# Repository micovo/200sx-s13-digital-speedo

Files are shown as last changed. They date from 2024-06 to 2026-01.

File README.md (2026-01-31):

# Nissan 180SX/200SX/240SX S13 Digital Speedo
This repository contains reverse-engineered schematics of Nissan S13 digital speedometer (VFD display).

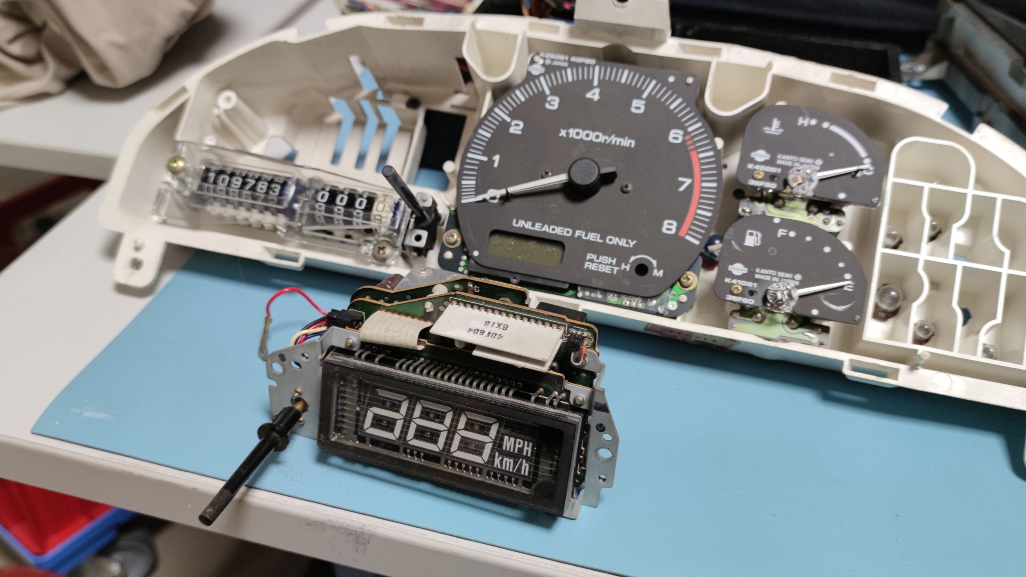
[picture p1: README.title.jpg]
Digital speedo foto Digital speedometer foto


The schematics description is available on my blog:

https://blog.michalhrouda.cz/2022/02/nissan-180sx-240sx-s13-digital-speedometer-schematics/

## Changelog

### REV3

- Project updated to KiCAD 9.0.0

- MainBoard - CONN1 and CONN2 numbering pattern fix to Nissan style (Second row of pins was mirrored)

- MainBoard, PowerBoard - HUD_2_POWER??? and HUD_3_POWER??? renamed to HUD_2_POWER and HUD_3_POWER (Confirmed by manual)

- PowerBoard - TRANS label added to transformer. It was not clear what "TRANS" in CONN6A1 signals description was referring to.

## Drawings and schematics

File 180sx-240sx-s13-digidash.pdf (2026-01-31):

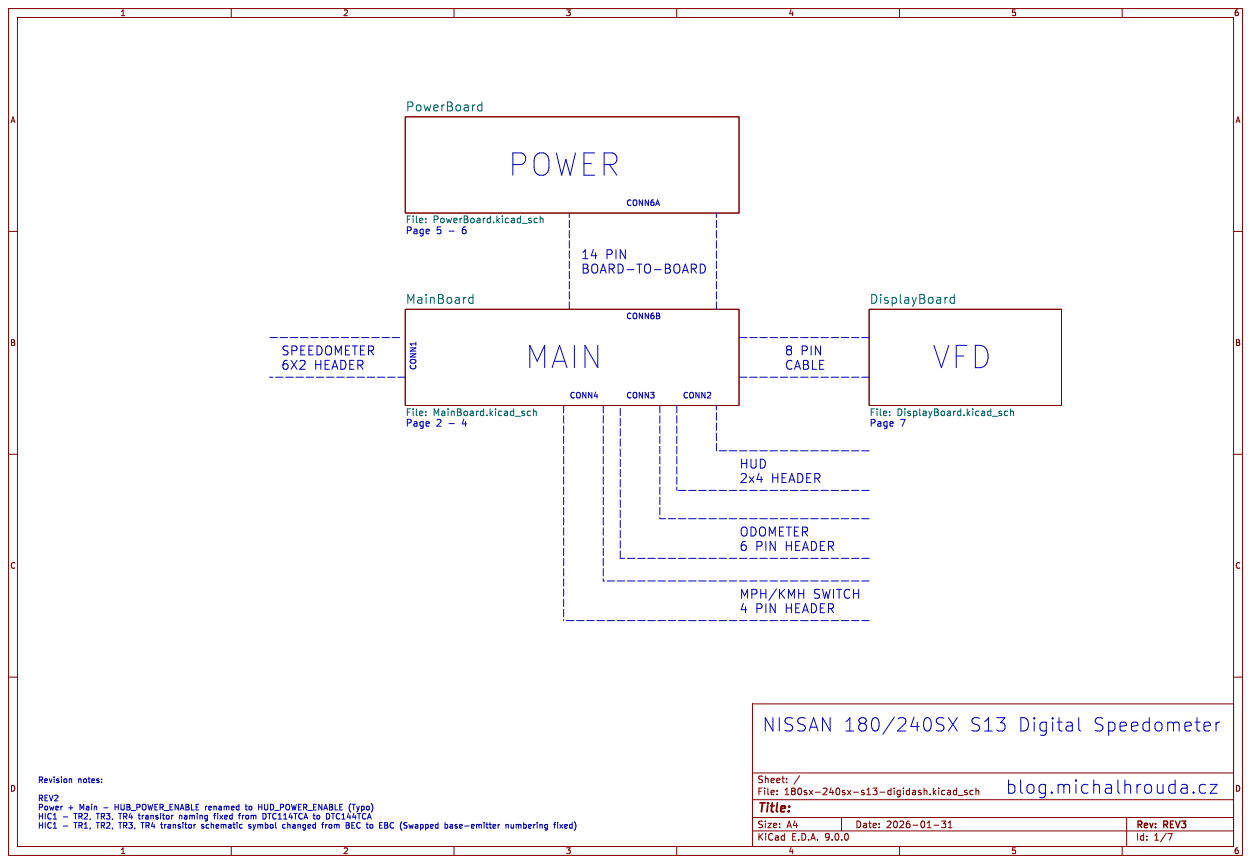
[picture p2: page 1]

Id: 1/7 Title: File: 180sx-240sx-s13-digidash.kicad_sch Sheet: /

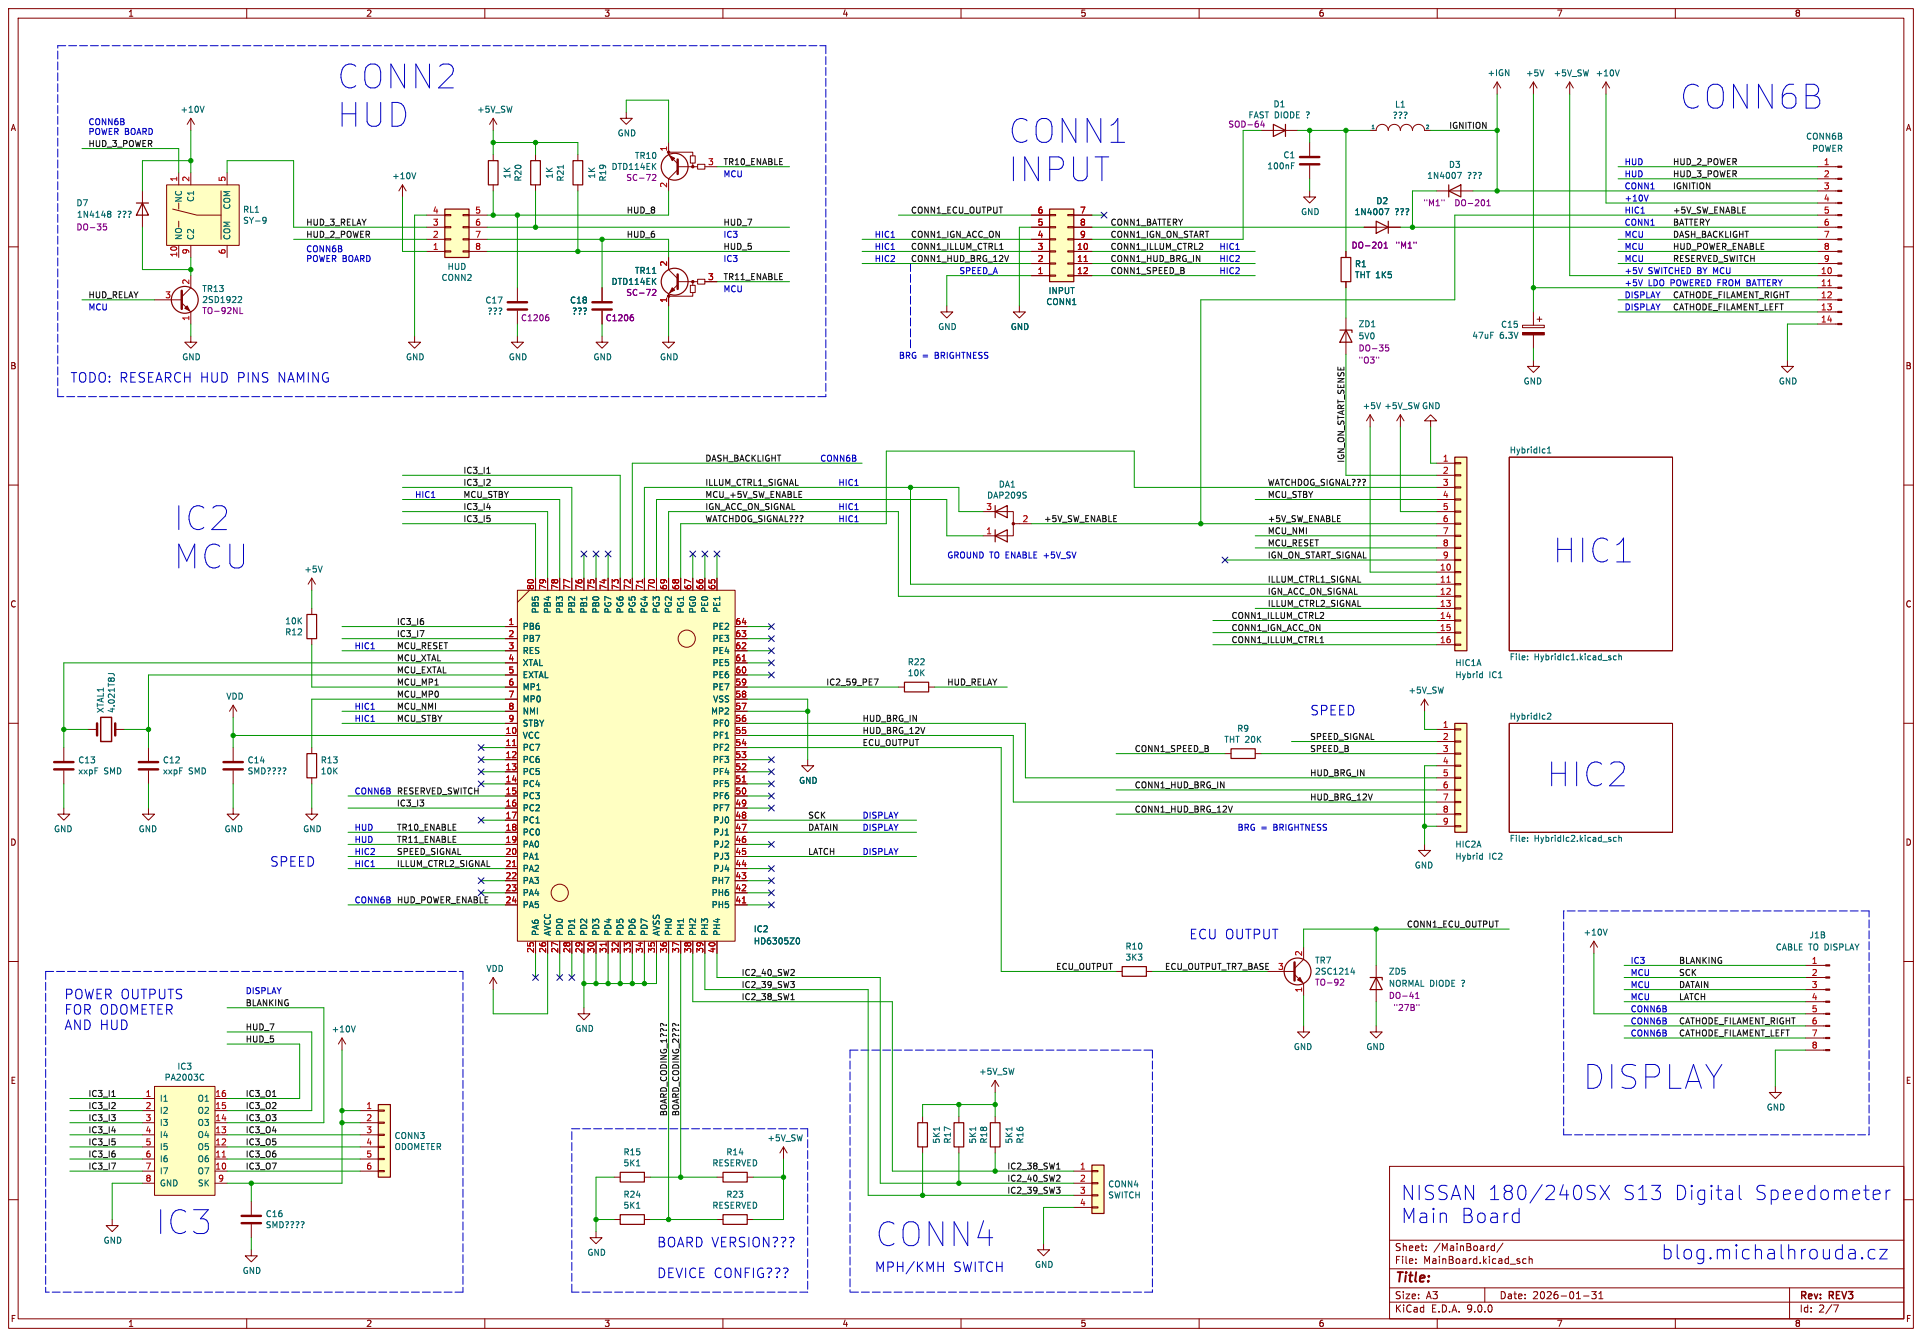
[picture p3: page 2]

SPEED_A DISPLAY MPH/KMH SWITCH

TODO: RESEARCH HUD PINS NAMING

J1B CABLE TO DISPLAY GND

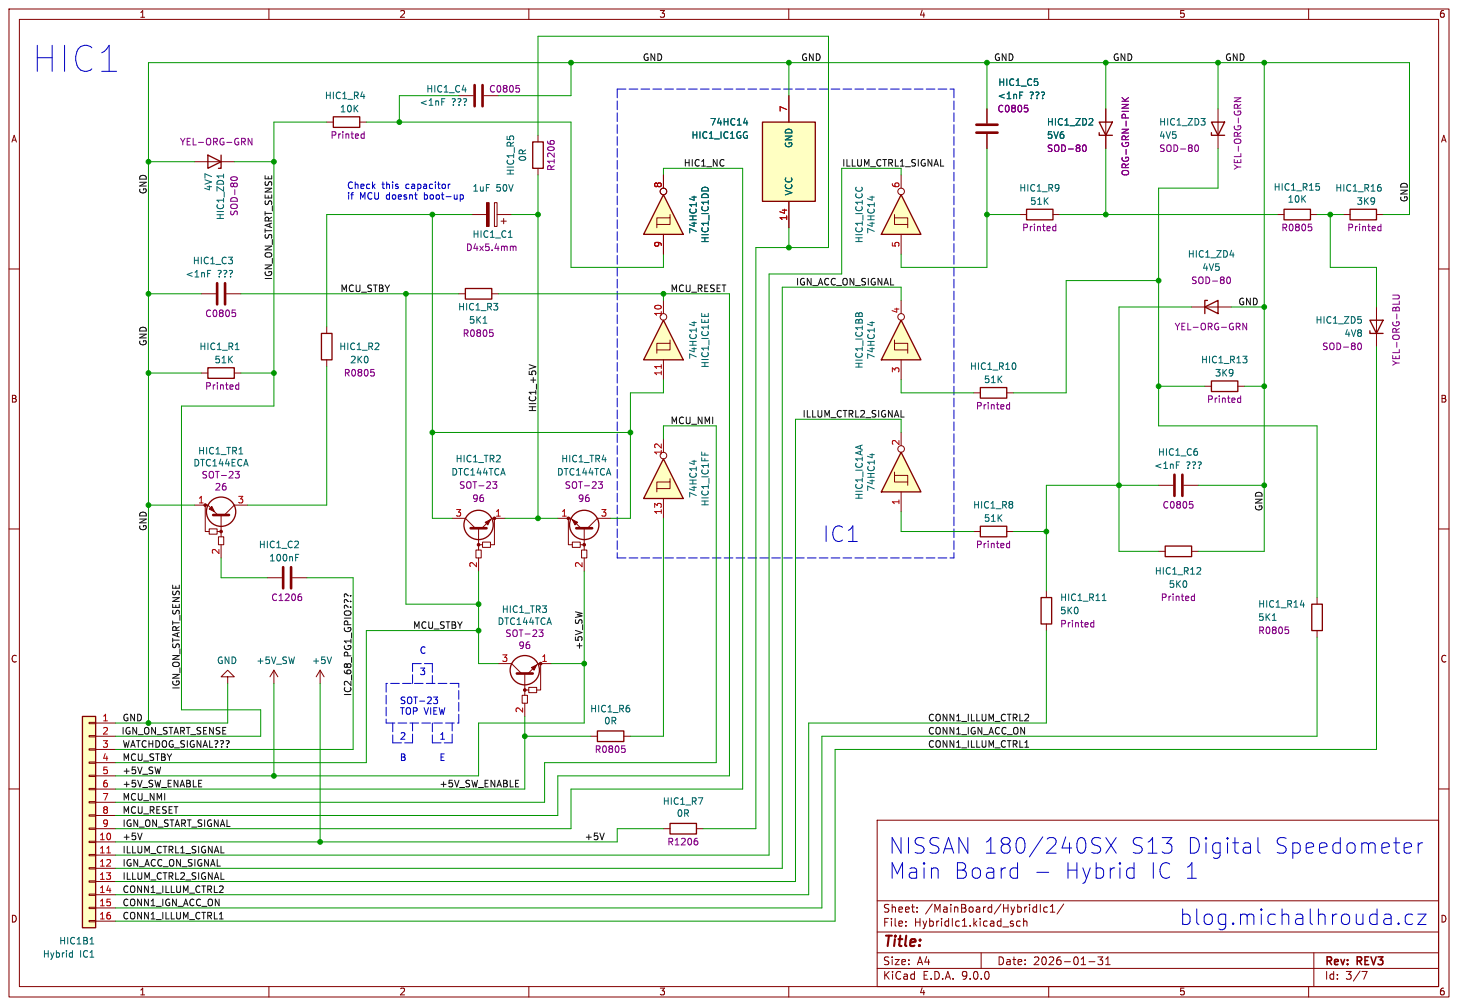
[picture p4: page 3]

Check this capacitor
if MCU doesnt boot-up
5K1 R0805 HIC1_C1

4V5 SOD-80 YEL-ORG-GRN

Main Board - Hybrid IC 1

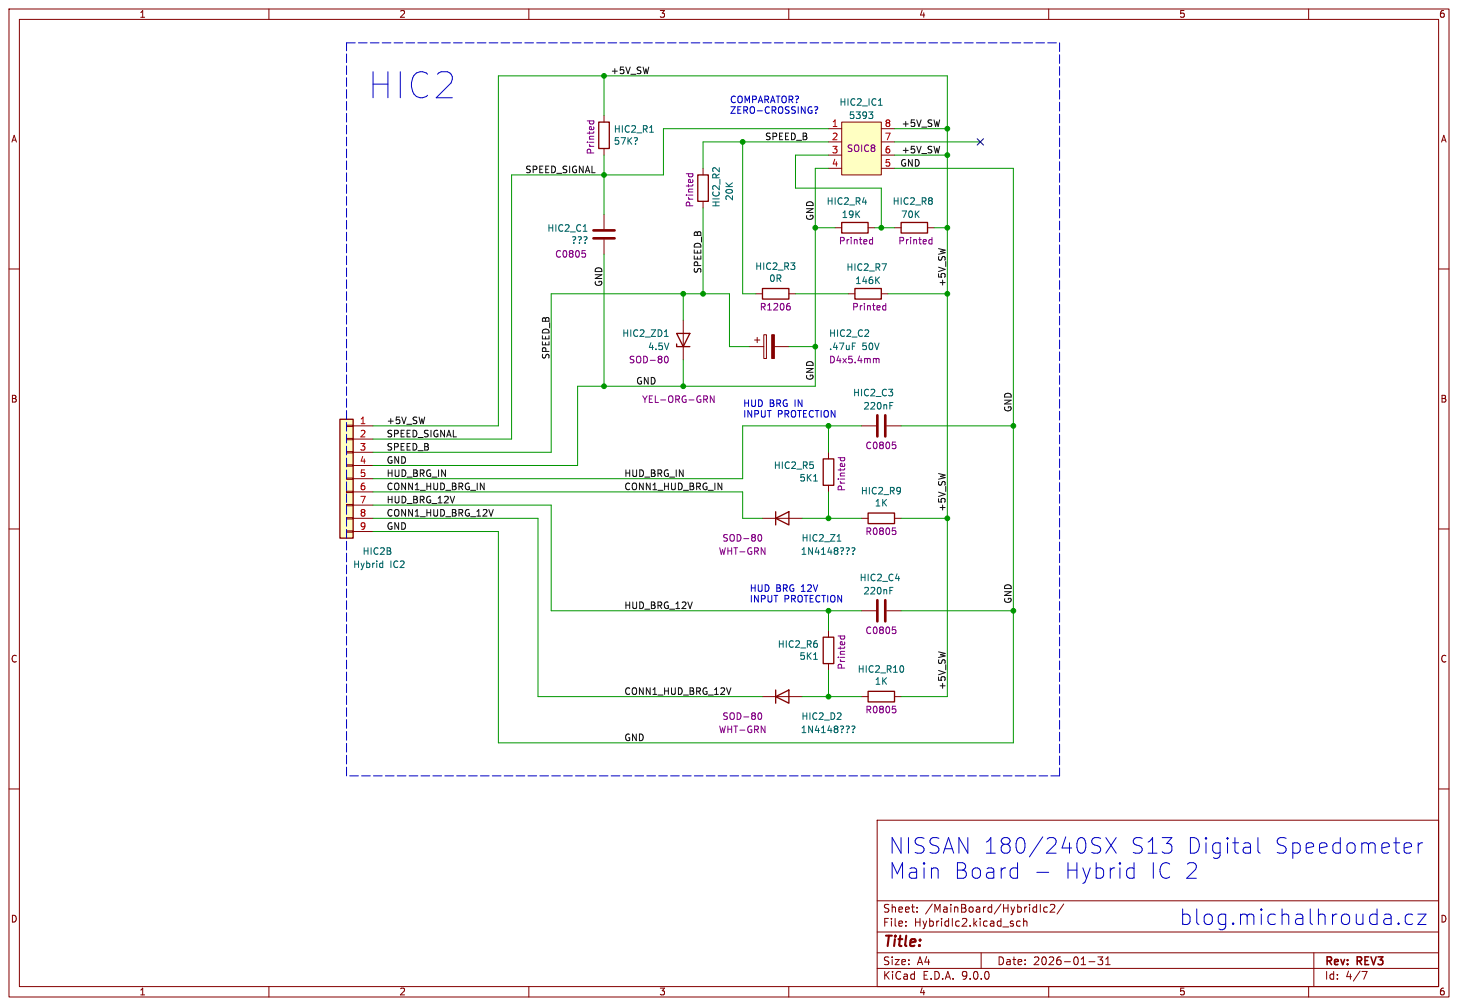
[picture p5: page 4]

SOD-80 YEL-ORG-GRN

Id: 4/7 Title: File: HybridIc2.kicad_sch Sheet: /MainBoard/HybridIc2/ HIC2_R9

Main Board - Hybrid IC 2

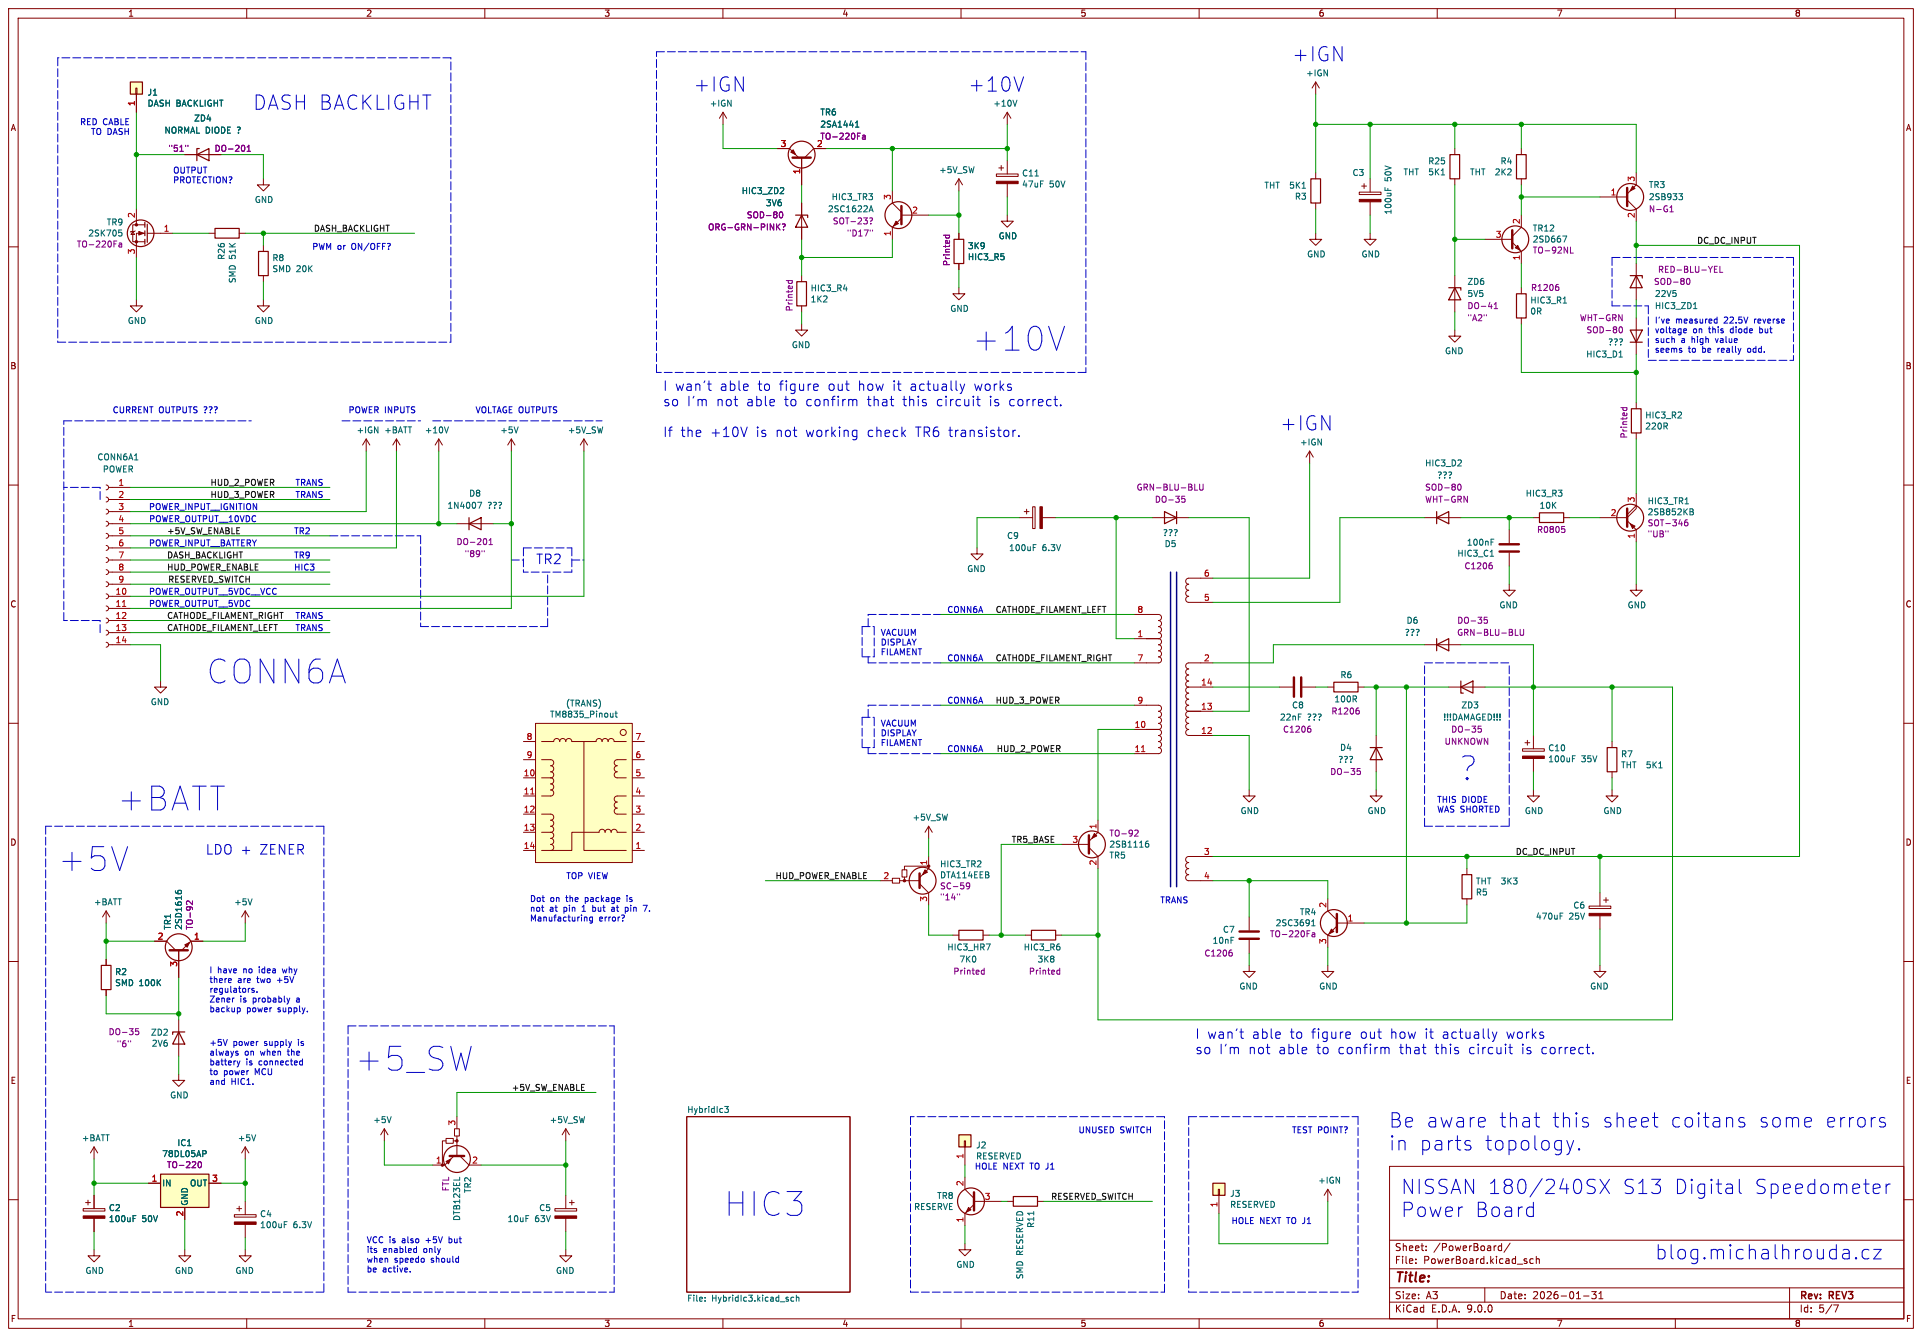
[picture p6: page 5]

OUTPUT PROTECTION? LDO + ZENER

seems to be really odd. +10V

3V6 SOD-80 ORG-GRN-PINK?

??? DO-35 GRN-BLU-BLU GND

HIC3_ZD1
I've measured 22.5V reverse
voltage on this diode but such a high value

??? SOD-80 WHT-GRN GND

so I'm not able to confirm that this circuit is correct.

If the +10V is not working check TR6 transistor.

!!!DAMAGED!!! DO-35 UNKNOWN GND

FILAMENT VCC is also +5V but

THIS DIODE WAS SHORTED

I have no idea why
there are two +5V

+5V power supply is always on when the

Be aware that this sheet coitans some errors
in parts topology.
Power Board

its enabled only when speedo should

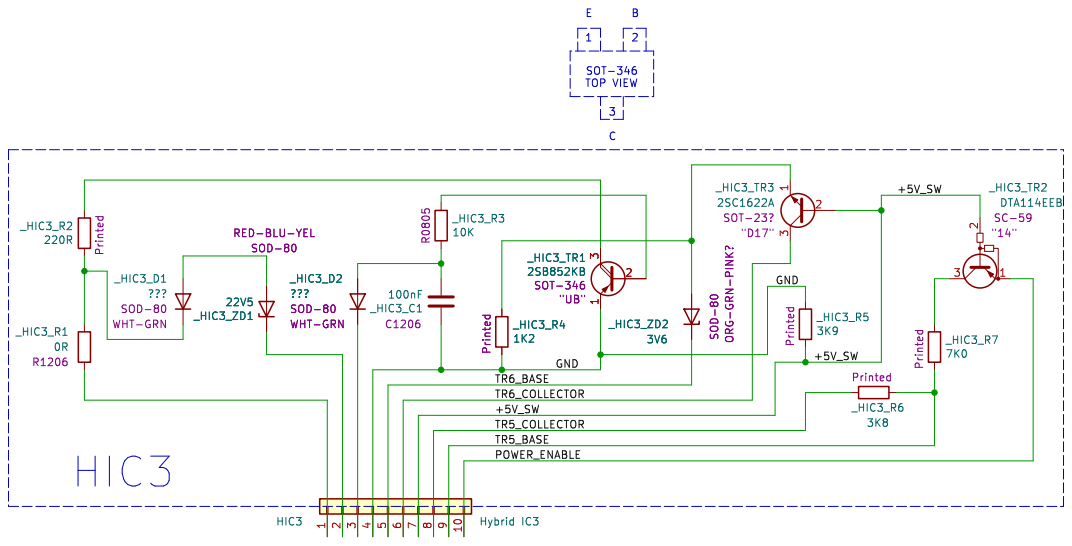
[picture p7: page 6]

Main Board - Hybrid IC 3

Id: 6/7 Title: File: HybridIc3.kicad_sch Sheet: /PowerBoard/HybridIc3/

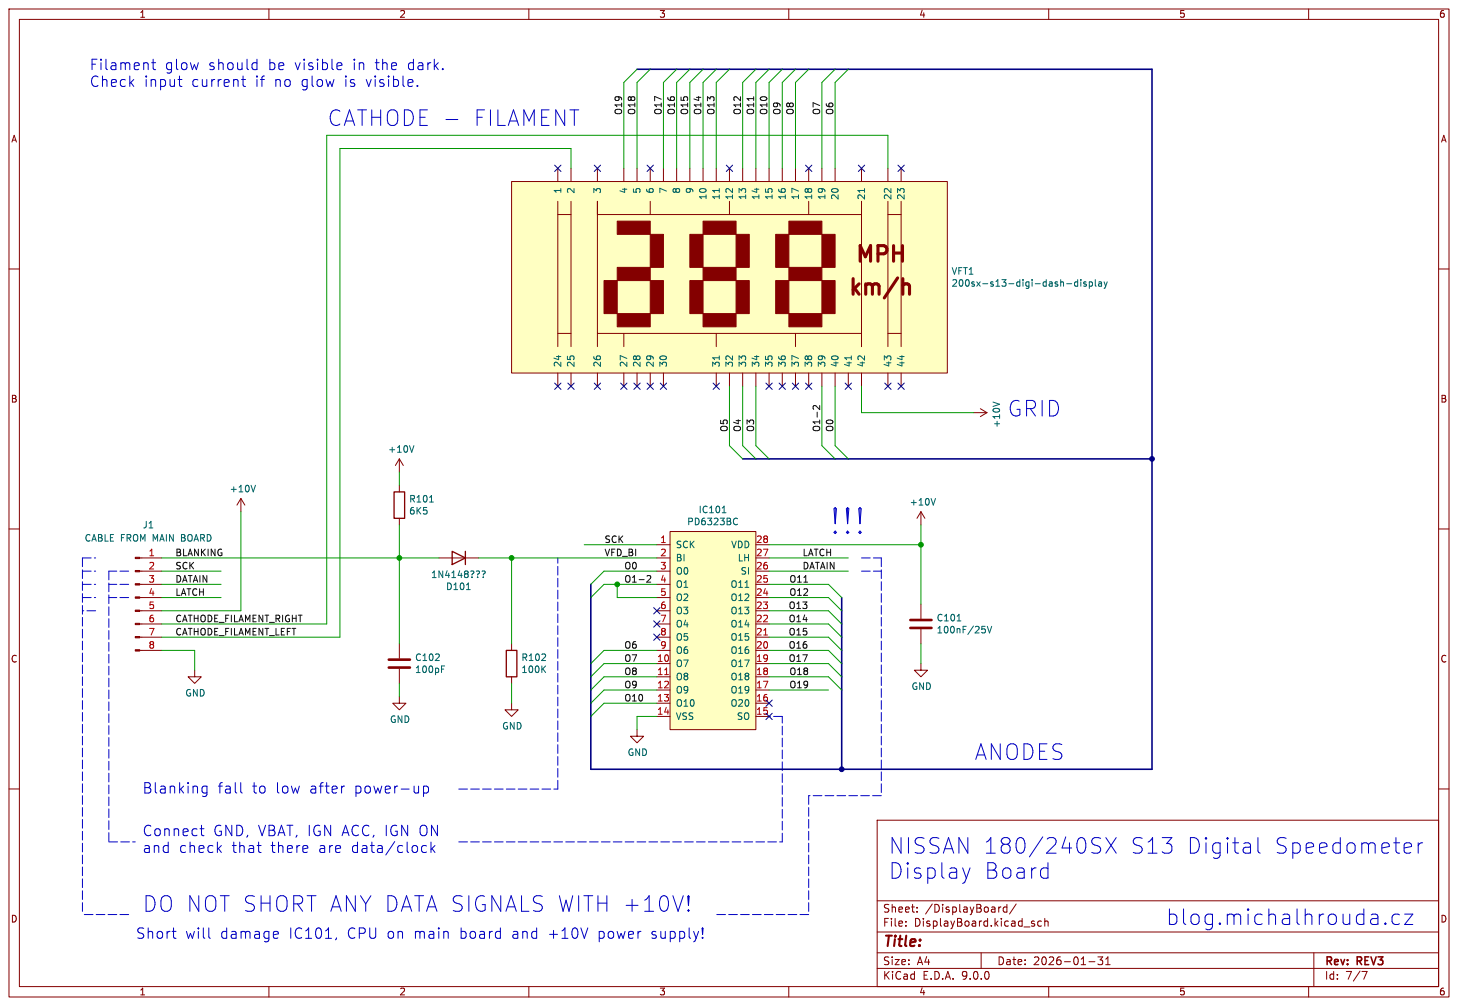
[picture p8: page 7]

Filament glow should be visible in the dark.
Check input current if no glow is visible.

J1 CABLE FROM MAIN BOARD

Id: 7/7 Title: File: DisplayBoard.kicad_sch Sheet: /DisplayBoard/ C102

Blanking fall to low after power-up

Connect GND, VBAT, IGN ACC, IGN ON
and check that there are data/clock

DO NOT SHORT ANY DATA SIGNALS WITH +10V!

Short will damage IC101, CPU on main board and +10V power supply!

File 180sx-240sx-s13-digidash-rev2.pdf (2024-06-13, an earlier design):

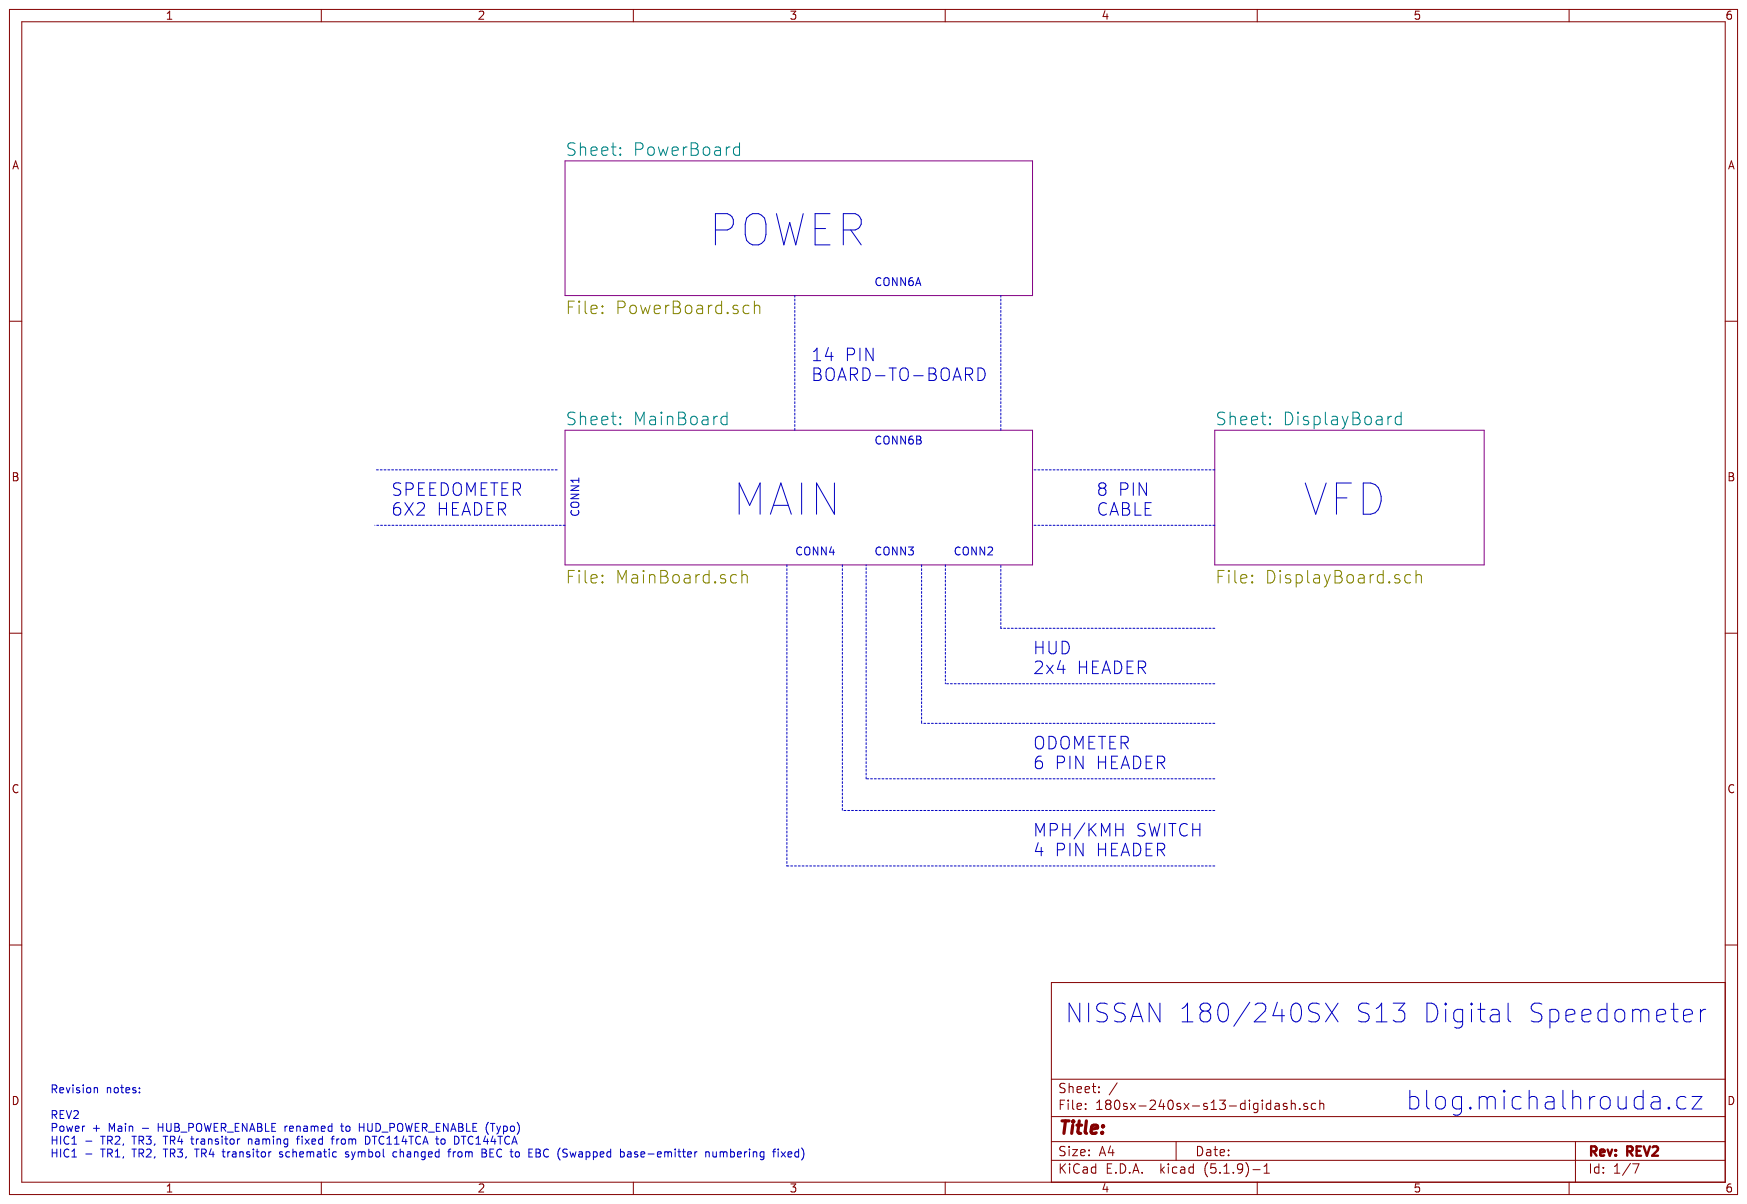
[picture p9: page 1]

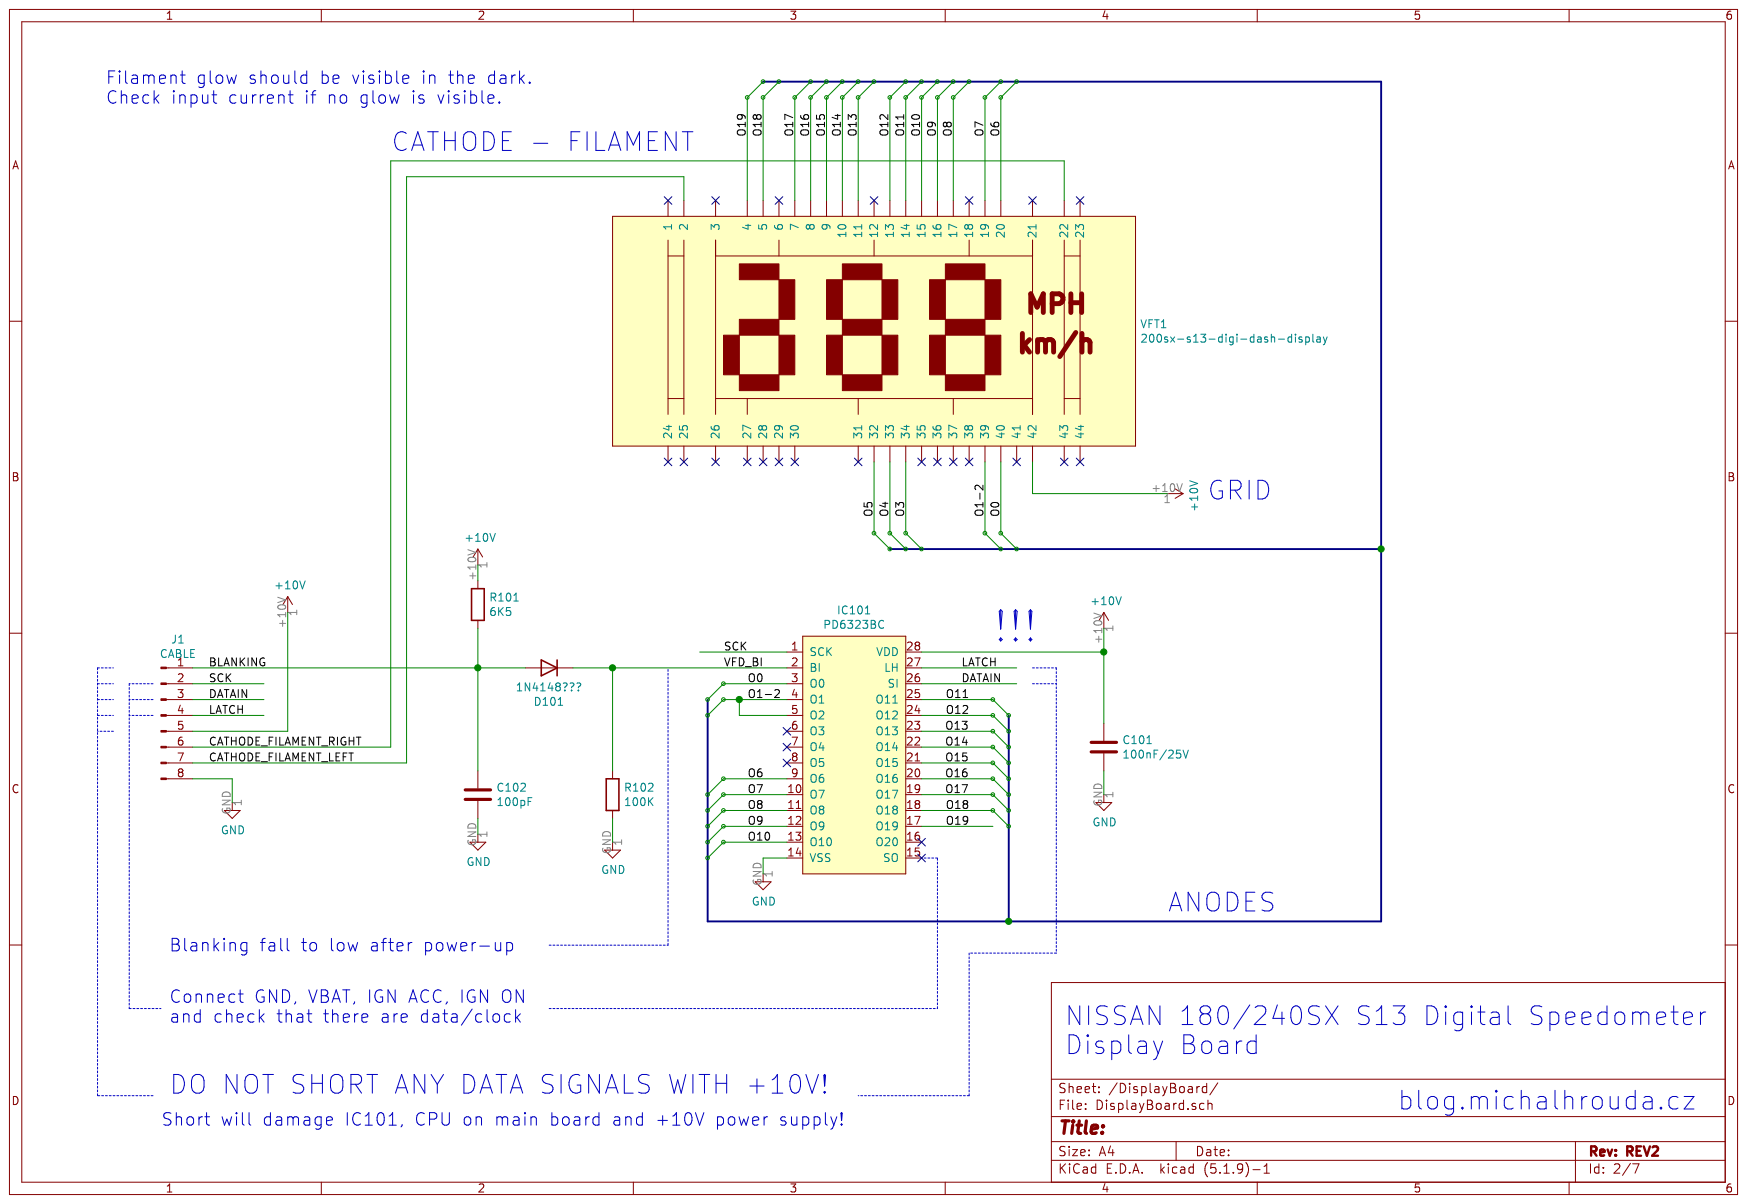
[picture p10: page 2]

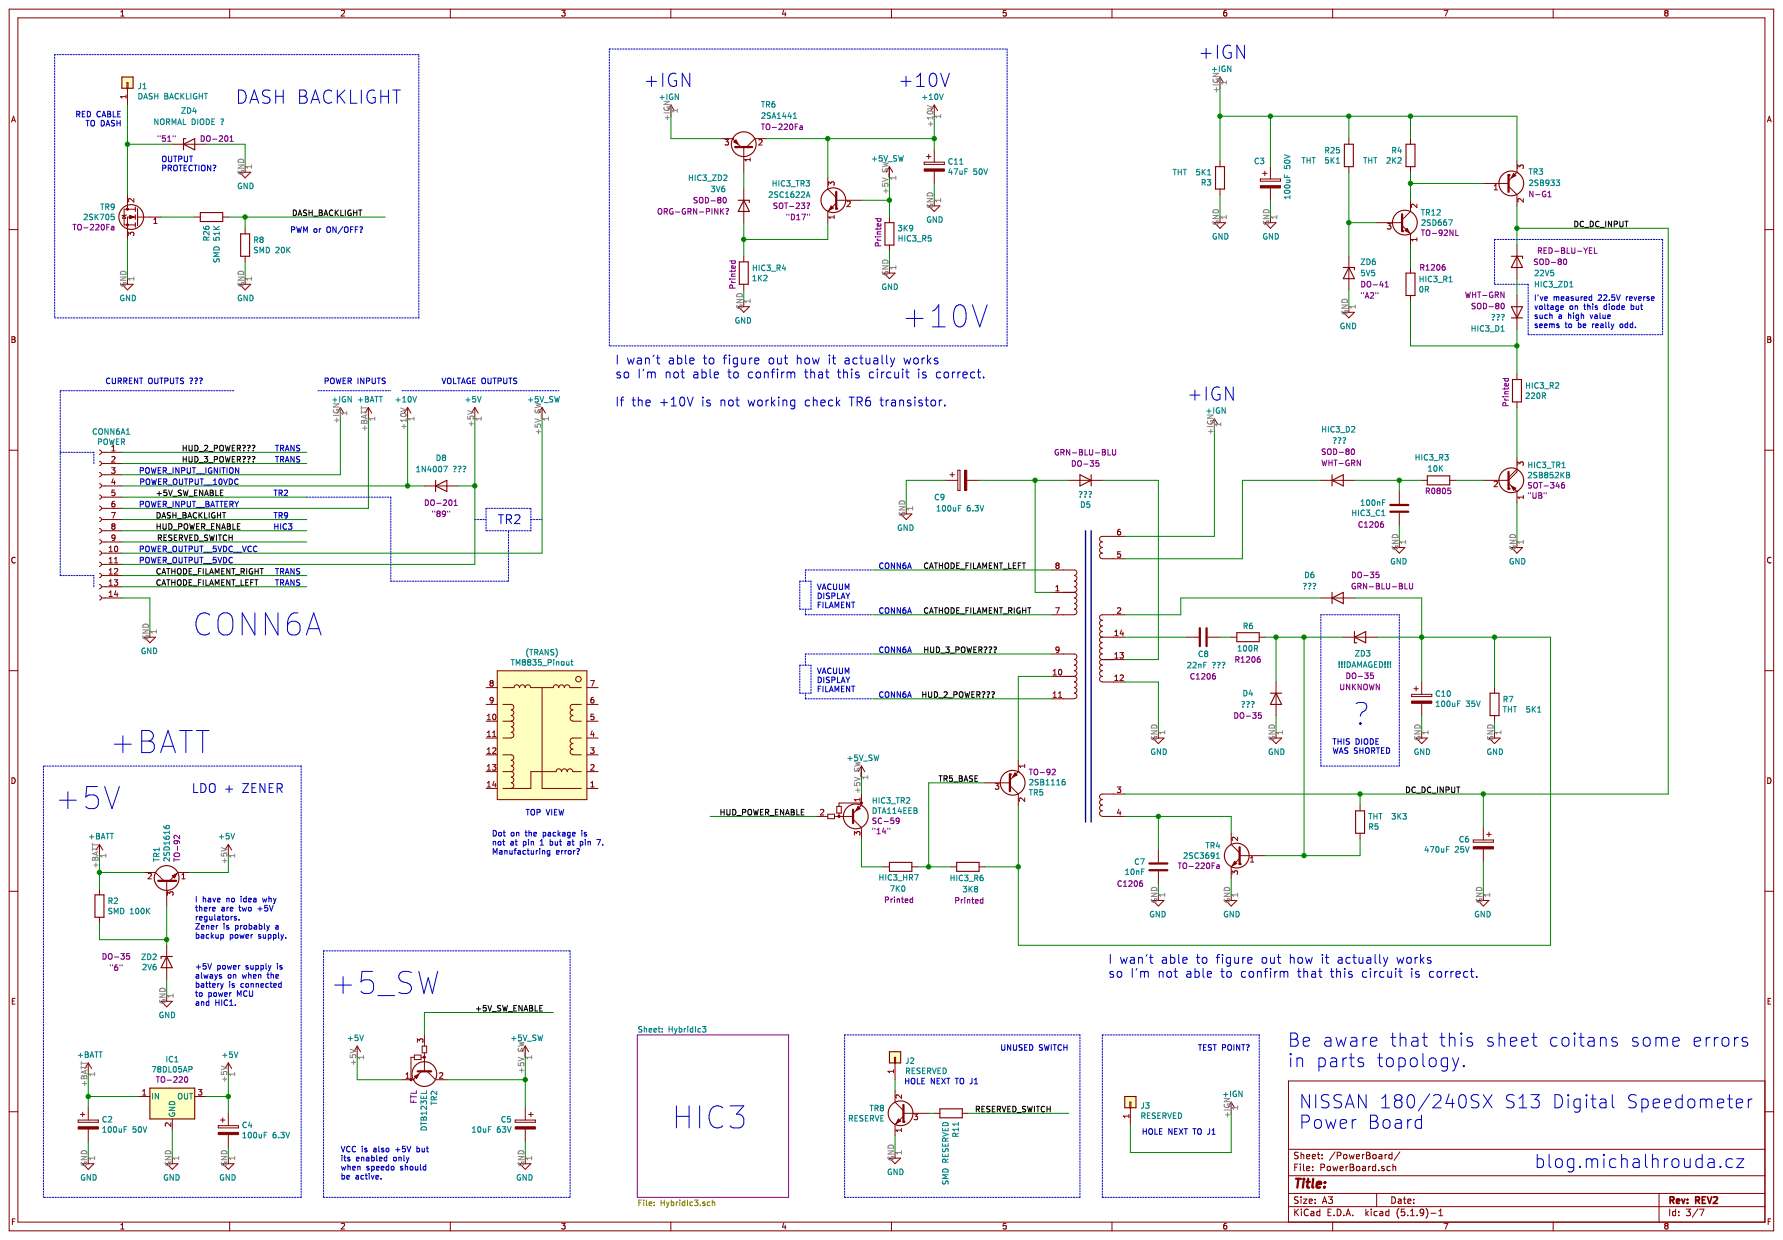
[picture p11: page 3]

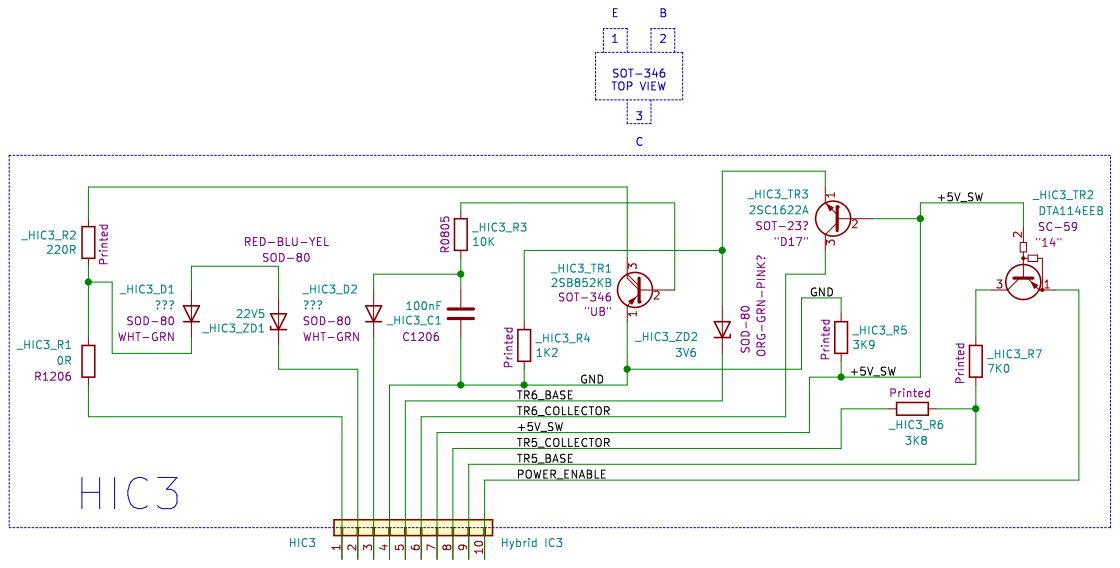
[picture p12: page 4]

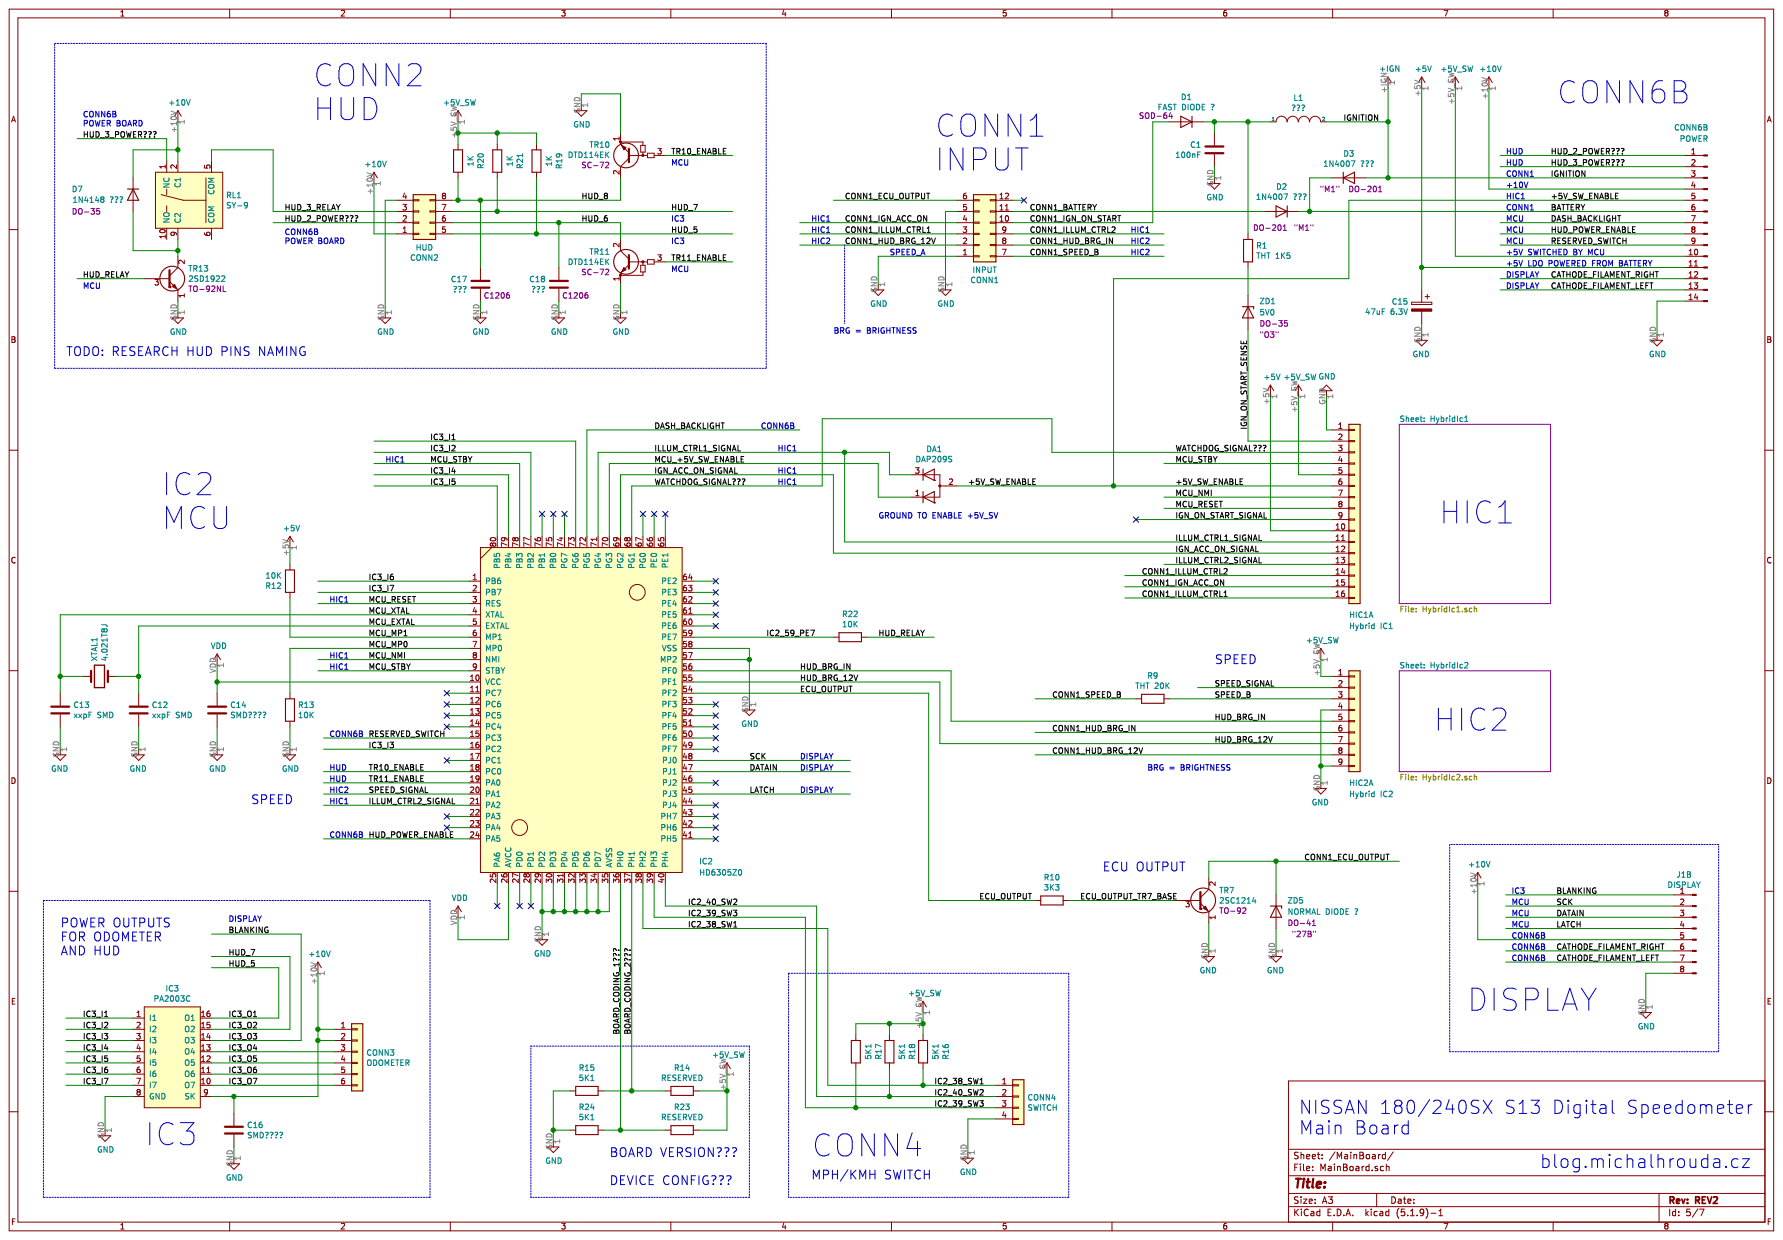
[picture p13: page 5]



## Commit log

2024-06-13 Initial commit.
    [180sx-240sx-s13-digidash.kicad_pcb, 180sx-240sx-s13-digidash.sch, DisplayBoard.sch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]
2026-01-31 REV3 - CONN1 and CONN2 fixed, HUD_2_POWER and HUD_3_POWER renamed, TRANS label added. Project updated to KiCAD 9.0.0.
    - MainBoard - CONN1 and CONN2 numbering pattern fix to Nissan style (Second row of pins was mirrored)
    - MainBoard, PowerBoard - HUD_2_POWER??? and HUD_3_POWER??? renamed to HUD_2_POWER and HUD_3_POWER (Confirmed by manual)
    - PowerBoard - TRANS label added to transformer. It was not clear what "TRANS" in CONN6A1 signals description was referring to.
    [180sx-240sx-s13-digidash.kicad_sch, 180sx-240sx-s13-digidash.sch, DisplayBoard.kicad_sch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]
2026-01-31 "REVx" removed from PDF name so its possible to make a link to the most recent file without need to update current rev number (on my blog/forums/etc.)
2026-01-31 Page order change and page numbers added to main block diagram.
    [180sx-240sx-s13-digidash.kicad_sch, MainBoard.kicad_sch, PowerBoard.kicad_sch]
